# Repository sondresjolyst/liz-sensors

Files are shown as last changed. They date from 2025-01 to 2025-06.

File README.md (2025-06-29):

# ReadTempAndHumidity

## Garge Voltmeter

Garge Voltmeter

### Voltage Divider Calculation for Wemos D1 Mini

To measure a higher voltage than 3.3V using the Wemos D1 Mini's ADC port, you can create a voltage divider with 47kΩ and 4.7kΩ resistors.

#### Voltage Divider Formula

$`V_{out} = V_{in} \times \frac{R2}{(R1 + R2)}`$

##### Precision

The Wemos D1 Mini's ADC can read voltages between 0 and 3.3V and gives a 10-bit reading (0-1024).
To calculate the minimum precision in voltage, one need to divide the maximum voltage by the ADC resolution:
$`\text{Minimum precision} = \frac{3.3V}{1024} \approx 0.00322V`$

The voltage at the ADC pin is approximately 9.09% of the input voltage. When the ADC reading changes by one step (e.g., from 366 to 365), the input voltage changes by:

$`\Delta V_{in} \approx \Delta V_{ADC} \times \frac{R1 + R2}{R2}`$

$`\Delta V_{in} \approx 0.00322V \times \frac{47k\Omega + 4.7k\Omega}{4.7k\Omega} \approx 0.0355V`$

#### Given Values

- $`R1 = 47kΩ`$ (47000Ω)
- $`R2 = 4.7kΩ`$ (4700Ω)
- $`V_{out} = 3.3V`$ (ADC input maximum)

#### Calculate Maximum

$`V_{in} = \frac{V_{out} \times (R1 + R2)}{R2}`$

Plugging in the values:

$`V_{in} = \frac{3.3V \times (47000Ω + 4700Ω)}{4700Ω}`$

$`V_{in} = 3.3V \times \frac{51700Ω}{4700Ω}`$

$`V_{in} \approx 36.3V`$

### Power Consumption Calculation

To estimate the power consumption of the Wemos D1 Mini:

#### Current Draw

Assuming an average current draw of 80mA (0.08A) when performing computations and connected to Wi-Fi.

#### Power Calculation

Using a 5V supply voltage:
$`\text{Power (P)} = \text{Voltage (V)} \times \text{Current (I)}`$

$`P = 5V \times 0.08A = 0.4W`$

#### Battery Life Estimation

With a 13V battery converted to 5V, taking into account the efficiency of the DC-DC converter (assumed to be 90% efficient):

$`\text{Effective Power Required} = \frac{\text{Power Consumption}}{\text{Efficiency}}`$

$`\text{Effective Power Required} = \frac{0.4W}{0.9} \approx 0.444W`$

#### Battery Current

$`I_{13V} = \frac{0.444W}{13V} \approx 0.034A = 34mA`$

#### Battery Capacity

If using a 13V motorcycle battery with a 6Ah (6000mAh) capacity:

Estimated Runtime:

$`\text{Runtime} = \frac{\text{Battery Capacity}}{\text{Current Draw}}`$

$`\text{Runtime} = \frac{6000mAh}{34mA} \approx 176 \, \text{hours}`$

To keep the battery above 40% charge, use only 60% of the battery's capacity:

$`\text{Usable Capacity} = 0.6 \times 72Wh = 43.2Wh`$

Revised Runtime:

$`\text{Runtime} = \frac{43.2Wh}{0.4W} = 108 \, \text{hours}`$

## Garge Sensor BME280

Garge Sensor BME280

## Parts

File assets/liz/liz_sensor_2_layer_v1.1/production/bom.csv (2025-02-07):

Designator | Footprint | Quantity | Value | LCSC Part #
BOOT1, RESET1 | PTS810SJG250SMTRLFS | 2 | PTS810SJM250SMTRLFS | C116501
C1, C3, C4, C7 | 0603 | 4 | 0.1uF | C108079
C10 | 0603 | 1 | 22uF | C86295
C2, C5, C6 | 0603 | 3 | 10uF | C95839
C9 | 0603 | 1 | 10uF | C3039688
D1 | D_SOD-123 | 1 | MM1Z3V3 | C22379456
D3 | 0603 | 1 | LED | C497940
D4, D6 | D_SOD-123 | 2 | B5817W | C7420328
J1 | USB_C_Receptacle_GCT_USB4105-xx-A_16P_TopMnt_Horizontal | 1 | USB_C_Receptacle_USB2.0_16P | C2988369
L2 | RES_CIGT201610_SAM | 1 | 2.2uH | C315717
PS1 | DSG0008A | 1 | TPS62163DSGR | C97534
R1, R2, R3, R8 | 0603 | 4 | 5.1k | C105580
R10, R11, R9 | 0603 | 3 | 10k | C98220
R4 | 0603 | 1 | 100k | C14675
R5 | 0603 | 1 | 33k | C126359
R6 | 0603 | 1 | 1M | C105578
R7 | 0603 | 1 | 200K | C105574
U1 | XCVR_ESP32-S3-MINI-1-N8 | 1 | ESP32-S3-MINI-1-N8 | C2913206
U2 | Diodes_UDFN-10_1.0x2.5mm_P0.5mm | 1 | D3V3XA4B10LP | C1980462
U5 | WSON-6-1EP_2x2mm_P0.65mm_EP1x1.6mm | 1 | TLV75801PDRVR | C2876308

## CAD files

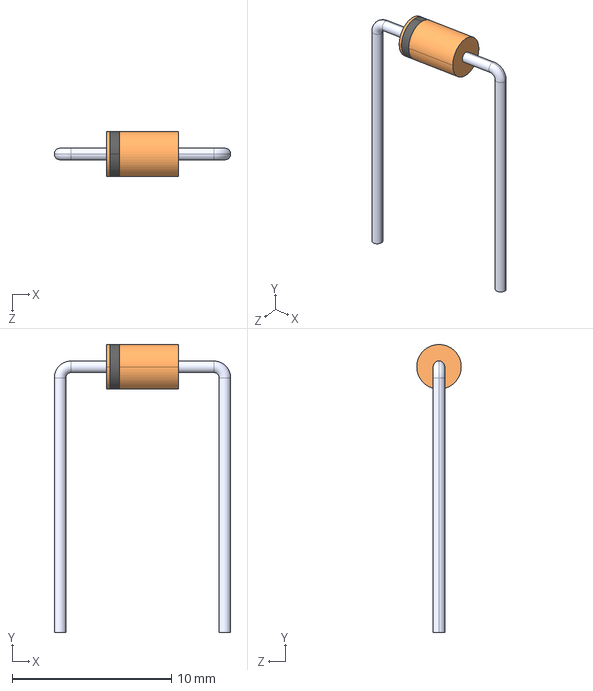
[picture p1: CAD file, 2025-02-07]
assets/kicad/DIOAD1036W78L470D235/1N5819.step
11.1 x 18.1 x 2.80 mm

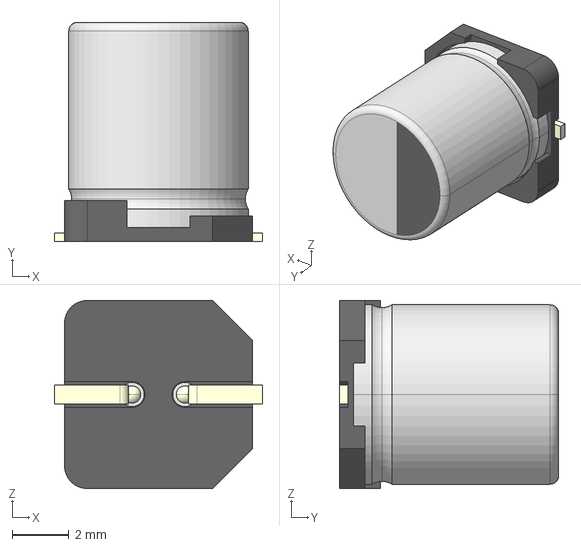
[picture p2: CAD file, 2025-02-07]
assets/kicad/EEE_FK1C221XP/6.3 SIZE CODE D8.stp
7.30 x 7.70 x 6.60 mm

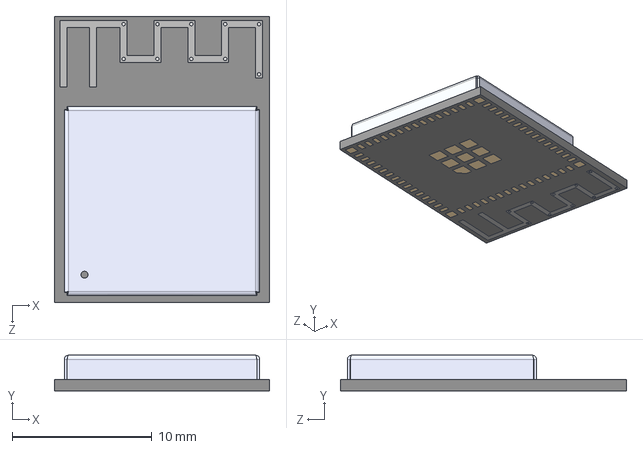
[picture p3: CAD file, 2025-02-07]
assets/kicad/ESP32_S3_MINI_1_N8/ESP32-S3-MINI-1-N8.step
15.4 x 2.55 x 20.5 mm

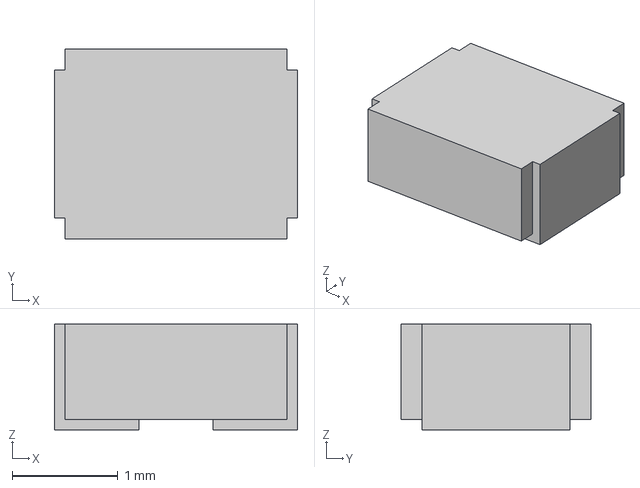
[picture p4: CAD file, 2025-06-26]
assets/kicad/INPAQ WIP201610P-2R2ML/INPAQ WIP201610P-2R2ML v1.step
2.30 x 1.80 x 1.00 mm

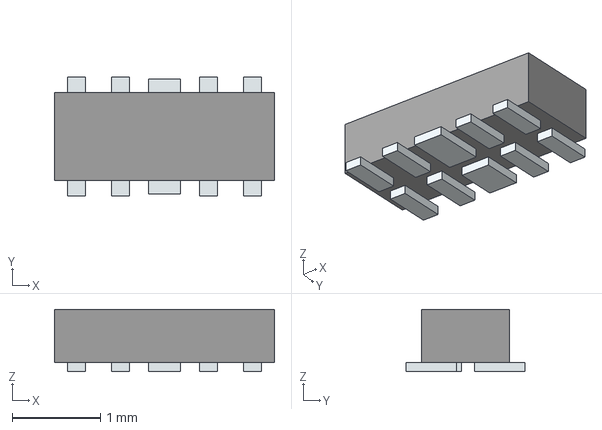
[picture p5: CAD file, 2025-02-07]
assets/kicad/LIB_D3V3XA4B10LP-7/3D_MODEL_D3V3XA4B10LP-7.stp
2.50 x 1.35 x 0.705 mm
Pins

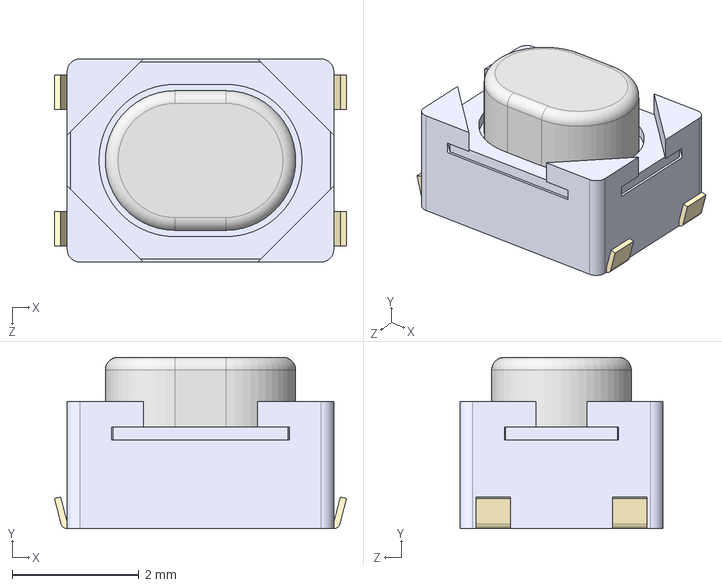
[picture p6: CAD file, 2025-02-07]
assets/kicad/PTS810_SJM_250_SMTR_LFS-1/PTS810_SJM_250_SMTR_LFS.step
4.60 x 2.70 x 3.20 mm

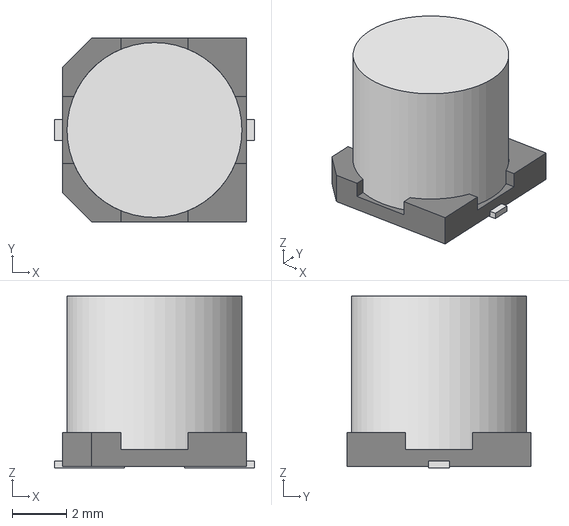
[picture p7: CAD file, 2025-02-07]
assets/kicad/UCD1C101MCL1GS/PCAP_6_3x5_8-ELECT_NCA.step
7.39 x 6.81 x 6.35 mm

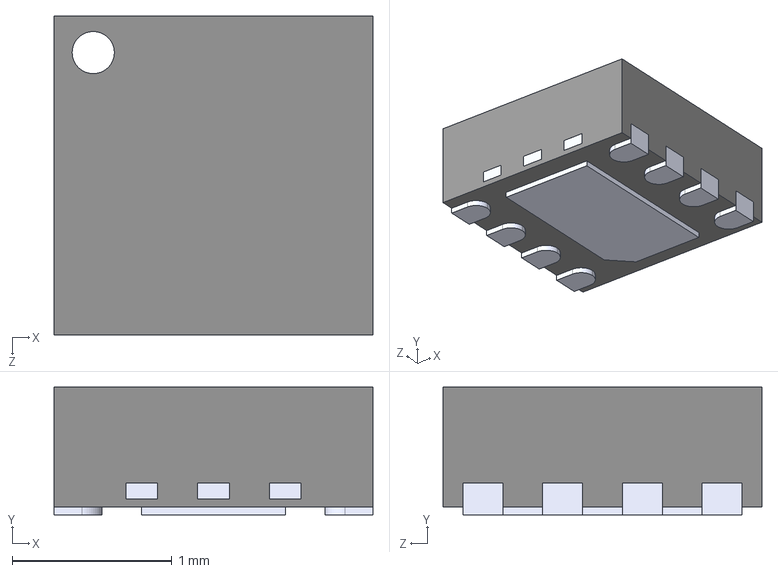
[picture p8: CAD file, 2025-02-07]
assets/kicad/TPS62163DSGR/TPS62163DSGR.step
2.00 x 0.8 x 2.00 mm

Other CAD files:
assets/kicad/PTS810SJK250SMTRLFS/PTS810SJK250SMTRLFS.step
assets/kicad/SW_SPST_PTS810/PTS810 SJK 250 SMTR LFS--3DModel-STEP-56544.STEP
assets/kicad/UCD1C101MCL1GS/PCAP_6_3x5_8-ELECT_NCA.stl

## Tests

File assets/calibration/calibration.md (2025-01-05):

# Calibration data

## Wemos_D1_Mini_30359b

vinTest: 5.34961, multimeter Voltage: 5.02
vinTest: 13.05305, multimeter Voltage: 12.46

b = (ln(12.46) - ln(5.02)) / (ln(13.05305) - ln(5.34961))
b = 1.01917

a = exp(ln(5.02) - b \* ln(5.34961))
a = 0.908698

## Wemos_D1_Mini_6ceb7b

vinTest: 5.31395, multimeter Voltage: 5.02
vinTest: 12.87473, multimeter Voltage: 12.46 !

b = (ln(12.46) - ln(5.02)) / (ln(12.87473) - ln(5.31395))
b = 1.0273

a = exp(ln(5.02) - b \* ln(5.31395))
a = 0.902573

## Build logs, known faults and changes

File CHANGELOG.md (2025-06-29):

# Changelog

## [1.2.0](https://github.com/sondresjolyst/liz-sensors/compare/v1.1.0...v1.2.0) (2025-06-29)

### Features

* deep sleep ([#52](https://github.com/sondresjolyst/liz-sensors/issues/52)) ([0139c0d](https://github.com/sondresjolyst/liz-sensors/commit/0139c0dd5e194e585fd49ba69620a2ce6850fd93))
* esp32 ([aac173f](https://github.com/sondresjolyst/liz-sensors/commit/aac173f91aa43422f035a25af99483b9dd24c71a))
* ota ([#42](https://github.com/sondresjolyst/liz-sensors/issues/42)) ([fa102e5](https://github.com/sondresjolyst/liz-sensors/commit/fa102e535304ba1b2b8679088578786951ce5ac2))
* reconnect wifi ([#41](https://github.com/sondresjolyst/liz-sensors/issues/41)) ([d379210](https://github.com/sondresjolyst/liz-sensors/commit/d379210903855eb51af8a8aa1a10627c74eb0c7d))
* restart esp after 30min in ap mode ([#47](https://github.com/sondresjolyst/liz-sensors/issues/47)) ([b1f367a](https://github.com/sondresjolyst/liz-sensors/commit/b1f367a2116ffc1238ec697edb8ca4a9438ff282))

## [1.1.0](https://github.com/sondresjolyst/ReadTempAndHumidity/compare/v1.0.0...v1.1.0) (2024-12-31)

### Features

* Add disconnect wifi button and update resistor values ([#16](https://github.com/sondresjolyst/ReadTempAndHumidity/issues/16)) ([7f7b2db](https://github.com/sondresjolyst/ReadTempAndHumidity/commit/7f7b2dbf6480bca77c49b0f49c84de614a5afcf4))
* clear discovered devices on mqtt connect ([#15](https://github.com/sondresjolyst/ReadTempAndHumidity/issues/15)) ([44b7ca9](https://github.com/sondresjolyst/ReadTempAndHumidity/commit/44b7ca900ee3a1d1843a49a8f0f2101eacec3b31))
* update liz library ([#13](https://github.com/sondresjolyst/ReadTempAndHumidity/issues/13)) ([82a56c5](https://github.com/sondresjolyst/ReadTempAndHumidity/commit/82a56c53015a5911a2f03a102e0812599baf3a18))
* voltmeter exponential correction ([#10](https://github.com/sondresjolyst/ReadTempAndHumidity/issues/10)) ([520e2b2](https://github.com/sondresjolyst/ReadTempAndHumidity/commit/520e2b2ddef42d0b414009e25ad73d3146d3929d))

## 1.0.0 (2024-11-24)

### Features

* add support for BME280 sensor ([93d0e8c](https://github.com/sondresjolyst/ReadTempAndHumidity/commit/93d0e8c4809605525ba1d0de92667ec27f99ab57))
* add voltmeter function ([ef76b20](https://github.com/sondresjolyst/ReadTempAndHumidity/commit/ef76b20ffd68cb40df00a7c2bb684850c44f1c26))
* restart ESP if temp or humid fail 10 times ([7d7e851](https://github.com/sondresjolyst/ReadTempAndHumidity/commit/7d7e85164cb90c81dfba13be1f3010f54c79e531))

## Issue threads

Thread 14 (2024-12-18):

subscribe to topic again after mosquitto server restart

sondresjolyst, 2024-12-18:
now it check if the connection is lost and reconnects, but it does not subscribe to the topic again.

this can be done by resetting discovered devices on reconnect or subscribing every discovery.
https://github.com/sondresjolyst/ReadTempAndHumidity/blob/82a56c53015a5911a2f03a102e0812599baf3a18/src/main.cpp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

Closed 2024-12-19.

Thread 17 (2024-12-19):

Rename repository

sondresjolyst, 2024-12-19:
The project now support voltage reading, temperature reading and humidity reading. Therefore the repository name should be changed to a more suitable name.

name ideas:
liz-sensors

Closed 2025-01-01.

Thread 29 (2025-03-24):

chore: add the possibility to change sensor name on build

sondresjolyst, 2025-03-24:
make it possible to change sensor name when building the image.
currently all sensors are named wemos_d1_mini... it should be possible wich is not always correct as liz-sensors now support esp32

sondresjolyst, 2025-08-10:
name is now dynamically built

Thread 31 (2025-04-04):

feat: Power sensor with own battery

sondresjolyst, 2025-04-04:
today liz uses 5v from USB or 12v from measuring connection.

look into adding a battery to the liz sensor.

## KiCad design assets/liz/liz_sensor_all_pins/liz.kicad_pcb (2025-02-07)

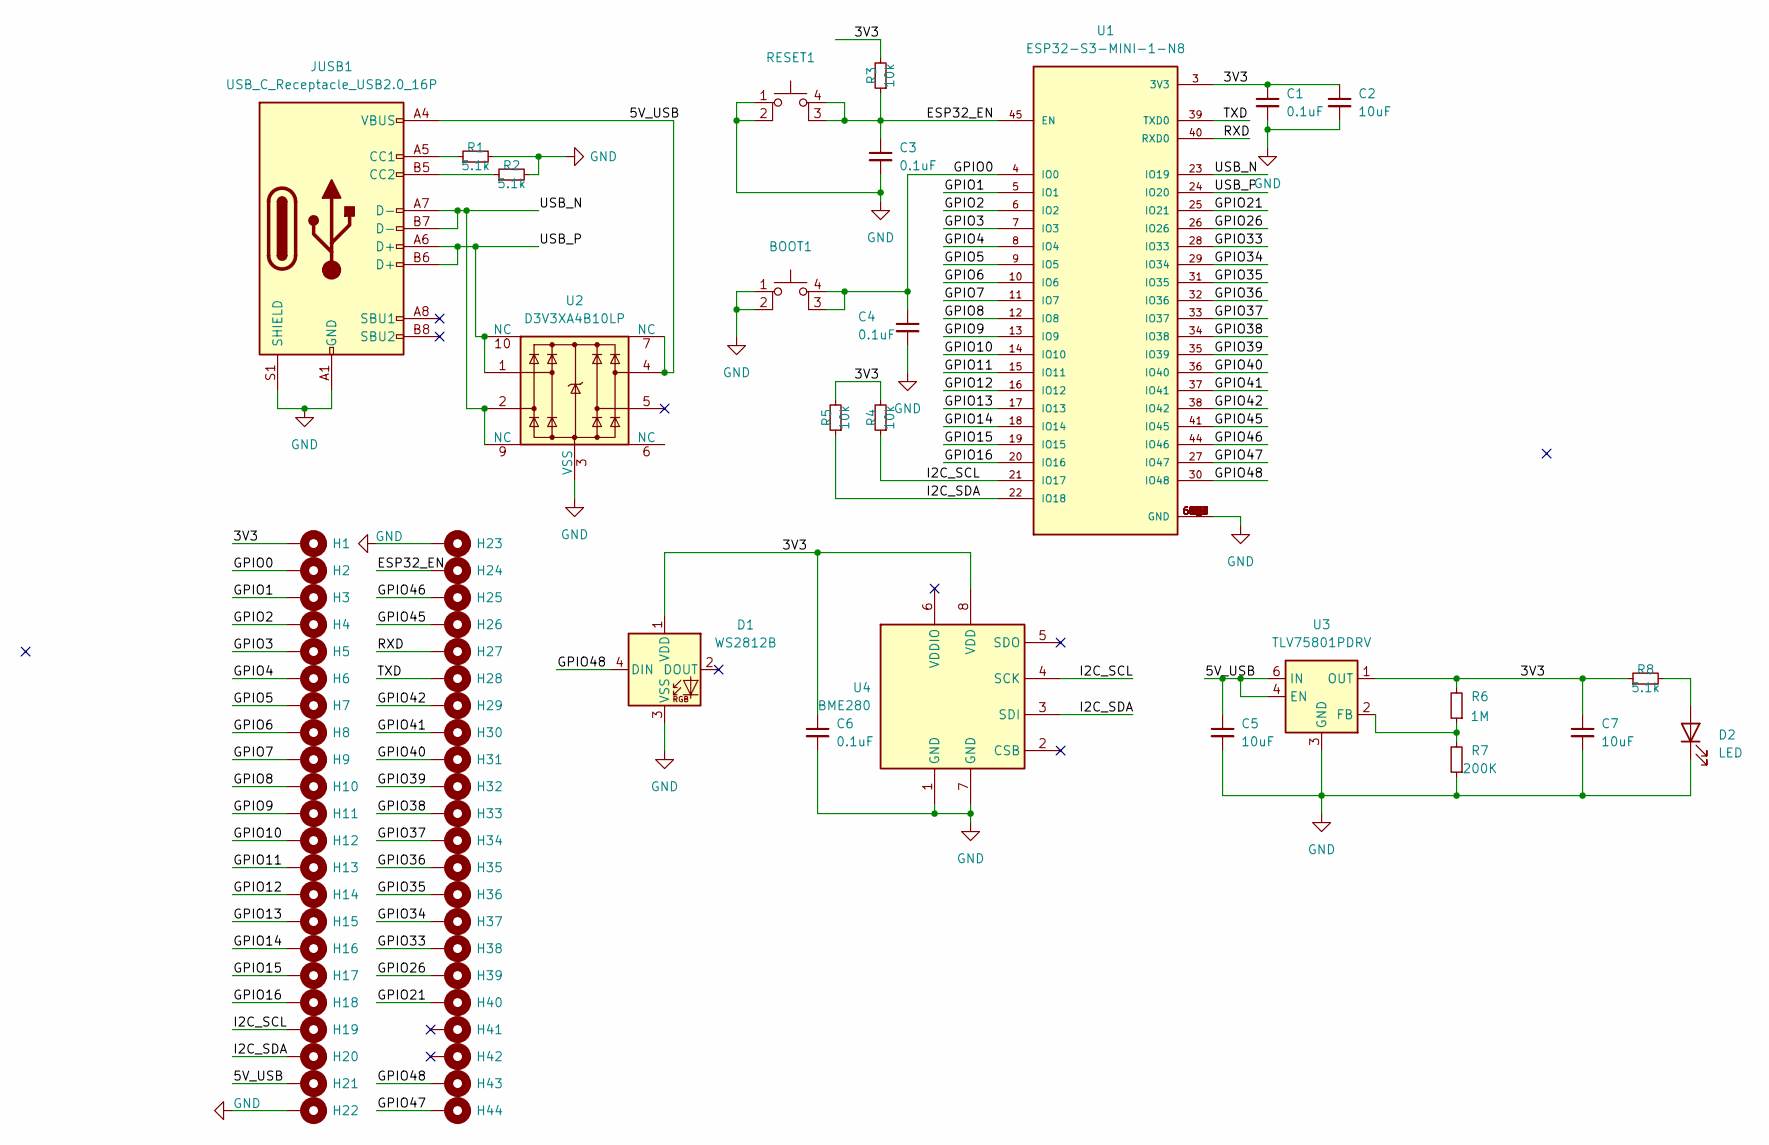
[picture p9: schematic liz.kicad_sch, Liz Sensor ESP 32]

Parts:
BOOT1: SW_SPST_PTS810
C1, C3, C4, C6: 0.1uF; C_0603_1608Metric
C2, C5, C7: 10uF; C_0603_1608Metric
D1: WS2812B; LED_WS2812B_PLCC4_5.0x5.0mm_P3.2mm
D2: LED; LED_0603_1608Metric
H1, H2, H3, H4, H5, H6, H7, H8, H9, H10, H11, H12, H13, H14, H15, H16, H17, H18, H19, H20, H21, H22, H23, H24, H25, H26, H27, H28, H29, H30, H31, H32, H33, H34, H35, H36, H37, H38, H39, H40, H41, H42, H43, H44: TestPoint_THTPad_D1.0mm_Drill0.5mm
JUSB1: USB_C_Receptacle_USB2.0_16P; USB_C_Receptacle_GCT_USB4105-xx-A_16P_TopMnt_Horizontal
R1, R2, R8: 5.1k; R_0603_1608Metric
R3, R4, R5: 10k; R_0603_1608Metric
R6: 1M; R_0603_1608Metric
R7: 200K; R_0603_1608Metric
RESET1: SW_SPST_PTS810
U1: ESP32-S3-MINI-1-N8; XCVR_ESP32-S3-MINI-1-N8; PARTREV v0.6
U2: D3V3XA4B10LP; Diodes_UDFN-10_1.0x2.5mm_P0.5mm
U3: TLV75801PDRV; WSON-6-1EP_2x2mm_P0.65mm_EP1x1.6mm
U4: BME280; Bosch_LGA-8_2.5x2.5mm_P0.65mm_ClockwisePinNumbering

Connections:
/3V3: C1.1, C2.1, C6.1, C7.1, D1.1 (VDD), H1.1, R3.2, R4.2, R5.2, R6.2, R8.1, U1.3 (3V3), U3.1 (OUT), U4.8 (VDD)
/5V_USB: C5.1, H21.1, JUSB1.A4 (VBUS), JUSB1.A9 (VBUS), JUSB1.B4 (VBUS), JUSB1.B9 (VBUS), U2.4, U2.7 (NC), U3.4 (EN), U3.6 (IN)
/ESP32_EN: C3.1, H24.1, R3.1, RESET1.3 (K), RESET1.4 (A), U1.45 (EN)
/GPIO0: BOOT1.3 (K), BOOT1.4 (A), C4.1, H2.1, U1.4 (IO0)
/GPIO1: H3.1, U1.5 (IO1)
/GPIO2: H4.1, U1.6 (IO2)
/GPIO3: H5.1, U1.7 (IO3)
/GPIO4: H6.1, U1.8 (IO4)
/GPIO5: H7.1, U1.9 (IO5)
/GPIO6: H8.1, U1.10 (IO6)
/GPIO7: H9.1, U1.11 (IO7)
/GPIO8: H10.1, U1.12 (IO8)
/GPIO9: H11.1, U1.13 (IO9)
/GPIO10: H12.1, U1.14 (IO10)
/GPIO11: H13.1, U1.15 (IO11)
/GPIO12: H14.1, U1.16 (IO12)
/GPIO13: H15.1, U1.17 (IO13)
/GPIO14: H16.1, U1.18 (IO14)
/GPIO15: H17.1, U1.19 (IO15)
/GPIO16: H18.1, U1.20 (IO16)
/GPIO21: H40.1, U1.25 (IO21)
/GPIO26: H39.1, U1.26 (IO26)
/GPIO33: H38.1, U1.28 (IO33)
/GPIO34: H37.1, U1.29 (IO34)
/GPIO35: H36.1, U1.31 (IO35)
/GPIO36: H35.1, U1.32 (IO36)
/GPIO37: H34.1, U1.33 (IO37)
/GPIO38: H33.1, U1.34 (IO38)
/GPIO39: H32.1, U1.35 (IO39)
/GPIO40: H31.1, U1.36 (IO40)
/GPIO41: H30.1, U1.37 (IO41)
/GPIO42: H29.1, U1.38 (IO42)
/GPIO45: H26.1, U1.41 (IO45)
/GPIO46: H25.1, U1.44 (IO46)
/GPIO47: H44.1, U1.27 (IO47)
/GPIO48: D1.4 (DIN), H43.1, U1.30 (IO48)
/I2C_SCL: H19.1, R4.1, U1.21 (IO17), U4.4 (SCK)
/I2C_SDA: H20.1, R5.1, U1.22 (IO18), U4.3 (SDI)
/RXD: H27.1, U1.40 (RXD0)
/TXD: H28.1, U1.39 (TXD0)
/USB_N: JUSB1.A7 (D-), JUSB1.B7 (D-), U1.23 (IO19), U2.2, U2.9 (NC)
/USB_P: JUSB1.A6 (D+), JUSB1.B6 (D+), U1.24 (IO20), U2.1, U2.10 (NC)
GND: BOOT1.1, BOOT1.2, C1.2, C2.2, C3.2, C4.2, C5.2, C6.2, C7.2, D1.3 (VSS), D2.1 (K), H22.1, H23.1, JUSB1.A1 (GND), JUSB1.A12 (GND), JUSB1.B1 (GND), JUSB1.B12 (GND), JUSB1.S1 (SHIELD), R1.2, R2.2, R7.1, RESET1.1, RESET1.2, U1.1 (GND), U1.2 (GND), U1.42 (GND), U1.43 (GND), U1.46 (GND), U1.47 (GND), U1.48 (GND), U1.49 (GND), U1.50 (GND), U1.51 (GND), U1.52 (GND), U1.53 (GND), U1.54 (GND), U1.55 (GND), U1.56 (GND), U1.57 (GND), U1.58 (GND), U1.59 (GND), U1.60 (GND), U1.61 (GND), U1.61_1 (GND), U1.61_2 (GND), U1.61_3 (GND), U1.61_4 (GND), U1.61_5 (GND), U1.61_6 (GND), U1.61_7 (GND), U1.61_8 (GND), U1.62 (GND), U1.63 (GND), U1.64 (GND), U1.65 (GND), U2.3 (VSS), U2.8 (VSS), U3.3 (GND), U3.7 (GND), U4.1 (GND), U4.7 (GND)
unnamed: D2.2 (A), R8.2
unnamed: JUSB1.A5 (CC1), R1.1
unnamed: JUSB1.B5 (CC2), R2.1
unnamed: R6.1, R7.2, U3.2 (FB)

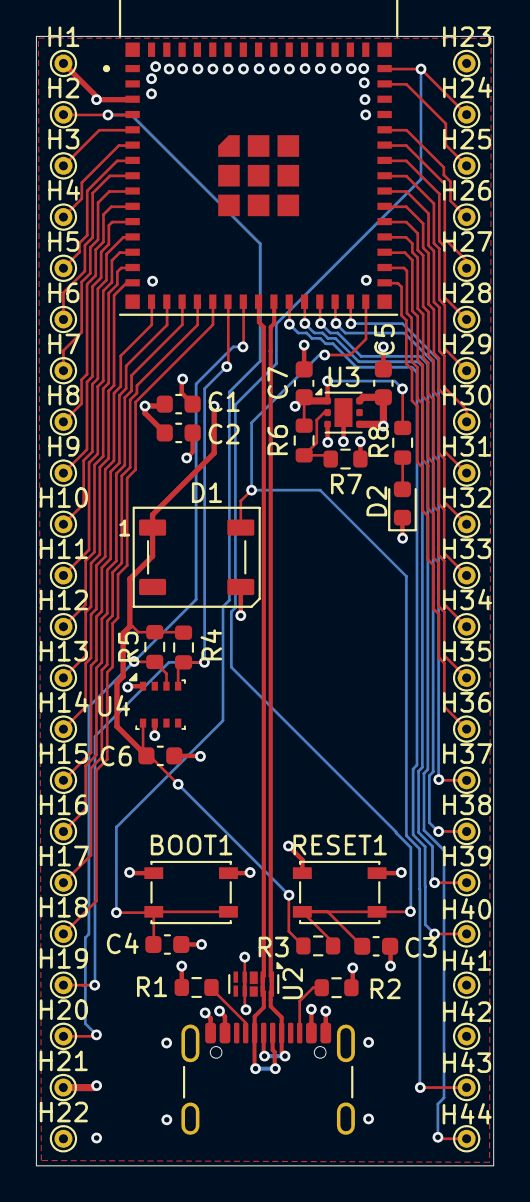
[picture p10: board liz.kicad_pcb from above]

Board: 4 copper layers, 25.4 x 62.7 mm, 68 parts (0 on the bottom side), 47 nets.

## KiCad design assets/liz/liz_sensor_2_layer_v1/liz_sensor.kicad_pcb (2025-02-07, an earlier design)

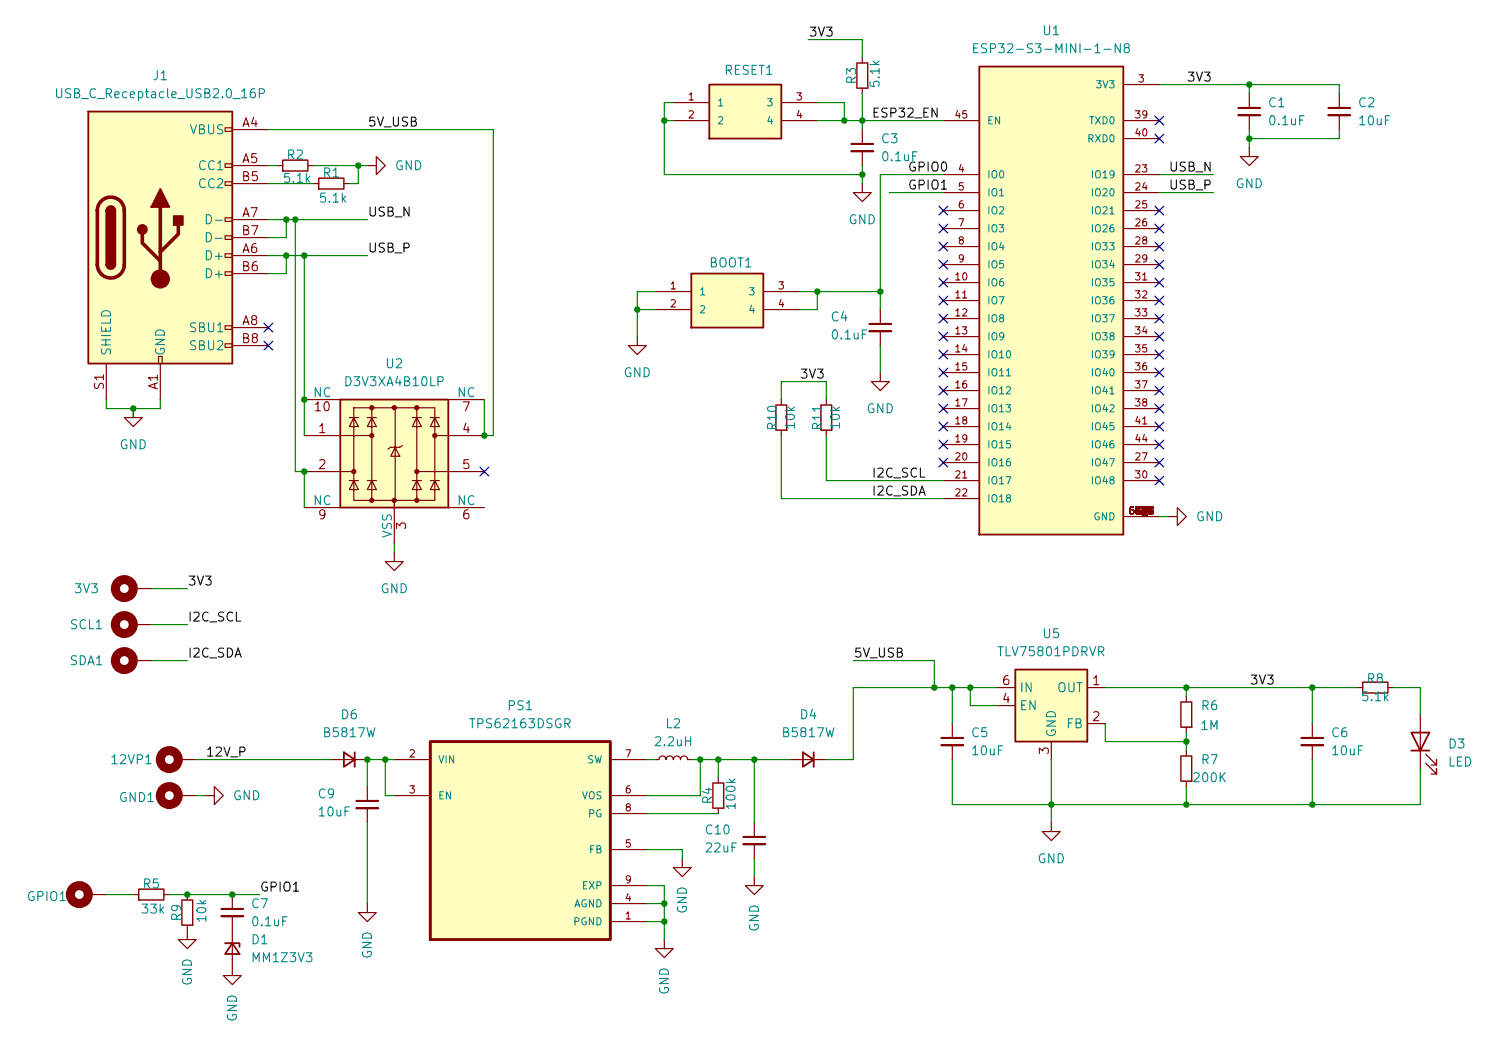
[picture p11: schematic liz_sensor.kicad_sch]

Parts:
3V3, 12VP1: TestPoint_THTPad_D1.0mm_Drill0.5mm
BOOT1: PTS810SJM250SMTRLFS; PTS810SJG250SMTRLFS; MANUFACTURER_PART_NUMBER PTS810SJK250SMTRLFS; JLCPCB Part # C116501
C1, C3, C4, C7: 0.1uF; C_0603_1608Metric; Part# CC0603KRX7R7BB104; JLCPCB Part # C108079
C2, C5, C6: 10uF; C_0603_1608Metric; Part# CL10A106KQ8NNNC; JLCPCB Part # C95839
C9: 10uF; C_0603_1608Metric; Part# CL10X106MO8NRNC; JLCPCB Part # C3039688
C10: 22uF; C_0603_1608Metric; Part# CL10A226MP8NUNE; JLCPCB Part # C86295
D1: MM1Z3V3; D_SOD-123; Part# MM1Z3V3; JLCPCB Part # C22379456
D3: LED; LED_0603_1608Metric; Part# HL-PST-1608H203BC; JLCPCB Part # C497940
D4, D6: B5817W; D_SOD-123; Part# B5817W; JLCPCB Part # C7420328
GND1: TestPoint_THTPad_D1.0mm_Drill0.5mm
GPIO1: TestPoint_THTPad_D1.0mm_Drill0.5mm
J1: USB_C_Receptacle_USB2.0_16P; USB_C_Receptacle_GCT_USB4105-xx-A_16P_TopMnt_Horizontal; Part# GT-USB-7010ASV; JLCPCB Part # C2988369
L2: 2.2uH; RES_CIGT201610_SAM; Part# WIP201610P-2R2ML; JLCPCB Part # C315717
PS1: TPS62163DSGR; DSG0008A; PARTREV E; JLCPCB Part # C97534
R1, R2, R3, R8: 5.1k; R_0603_1608Metric; Part# RC0603FR-075K1L; JLCPCB Part # C105580
R4: 100k; R_0603_1608Metric; Part# RC0603FR-07100KL; JLCPCB Part # C14675
R5: 33k; R_0603_1608Metric; Part# RC0603FR-0733KL; JLCPCB Part # C126359
R6: 1M; R_0603_1608Metric; Part# RC0603FR-071ML; JLCPCB Part # C105578
R7: 200K; R_0603_1608Metric; Part# RC0603FR-07200KL; JLCPCB Part # C105574
R9, R10, R11: 10k; R_0603_1608Metric; Part# RC0603FR-0710KL; JLCPCB Part # C98220
RESET1: PTS810SJM250SMTRLFS; PTS810SJG250SMTRLFS; MANUFACTURER_PART_NUMBER PTS810SJK250SMTRLFS; JLCPCB Part # C116501
SCL1: TestPoint_THTPad_D1.0mm_Drill0.5mm
SDA1: TestPoint_THTPad_D1.0mm_Drill0.5mm
U1: ESP32-S3-MINI-1-N8; XCVR_ESP32-S3-MINI-1-N8; PARTREV v0.6; JLCPCB Part # C2913206
U2: D3V3XA4B10LP; Diodes_UDFN-10_1.0x2.5mm_P0.5mm; Part# D3V3XA4B10LP-7; JLCPCB Part # C1980462
U5: TLV75801PDRVR; WSON-6-1EP_2x2mm_P0.65mm_EP1x1.6mm; Part# TLV75801PDRVR; JLCPCB Part # C2876308

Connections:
/3V3: 3V3.1, C1.1, C2.1, C6.1, R3.2, R6.2, R8.1, R10.2, R11.2, U1.3 (3V3), U5.1 (OUT)
/5V_USB: C5.1, D4.1 (K), J1.A4 (VBUS), J1.A9 (VBUS), J1.B4 (VBUS), J1.B9 (VBUS), U2.4, U2.7 (NC), U5.4 (EN), U5.6 (IN)
/12V_P: 12VP1.1, D6.2 (A)
/ESP32_EN: C3.1, R3.1, RESET1.3, RESET1.4, U1.45 (EN)
/GPIO0: BOOT1.3, BOOT1.4, C4.1, U1.4 (IO0)
/GPIO1: C7.1, R5.2, R9.2, U1.5 (IO1)
/I2C_SCL: R11.1, SCL1.1, U1.21 (IO17)
/I2C_SDA: R10.1, SDA1.1, U1.22 (IO18)
/USB_N: J1.A7 (D-), J1.B7 (D-), U1.23 (IO19), U2.2, U2.9 (NC)
/USB_P: J1.A6 (D+), J1.B6 (D+), U1.24 (IO20), U2.1, U2.10 (NC)
GND: BOOT1.1, BOOT1.2, C1.2, C2.2, C3.2, C4.2, C5.2, C6.2, C9.2, C10.2, D1.2 (A), D3.1 (K), GND1.1, J1.A1 (GND), J1.A12 (GND), J1.B1 (GND), J1.B12 (GND), J1.S1 (SHIELD), PS1.1 (PGND), PS1.4 (AGND), PS1.5 (FB), PS1.9 (EXP), PS1.V, R1.2, R2.2, R7.1, R9.1, RESET1.1, RESET1.2, U1.1 (GND), U1.2 (GND), U1.42 (GND), U1.43 (GND), U1.46 (GND), U1.47 (GND), U1.48 (GND), U1.49 (GND), U1.50 (GND), U1.51 (GND), U1.52 (GND), U1.53 (GND), U1.54 (GND), U1.55 (GND), U1.56 (GND), U1.57 (GND), U1.58 (GND), U1.59 (GND), U1.60 (GND), U1.61 (GND), U1.61_1 (GND), U1.61_2 (GND), U1.61_3 (GND), U1.61_4 (GND), U1.61_5 (GND), U1.61_6 (GND), U1.61_7 (GND), U1.61_8 (GND), U1.62 (GND), U1.63 (GND), U1.64 (GND), U1.65 (GND), U2.3 (VSS), U2.8 (VSS), U5.3 (GND), U5.7 (GND)
unnamed: C7.2, D1.1 (K)
unnamed: D3.2 (A), R8.2
unnamed: C10.1, D4.2 (A), L2.2, PS1.6 (VOS), R4.2
unnamed: C9.1, D6.1 (K), PS1.2 (VIN), PS1.3 (EN)
unnamed: GPIO1.1, R5.1
unnamed: J1.A5 (CC1), R2.1
unnamed: J1.B5 (CC2), R1.1
unnamed: PS1.8 (PG), R4.1
unnamed: L2.1, PS1.7 (SW)
unnamed: R6.1, R7.2, U5.2 (FB)

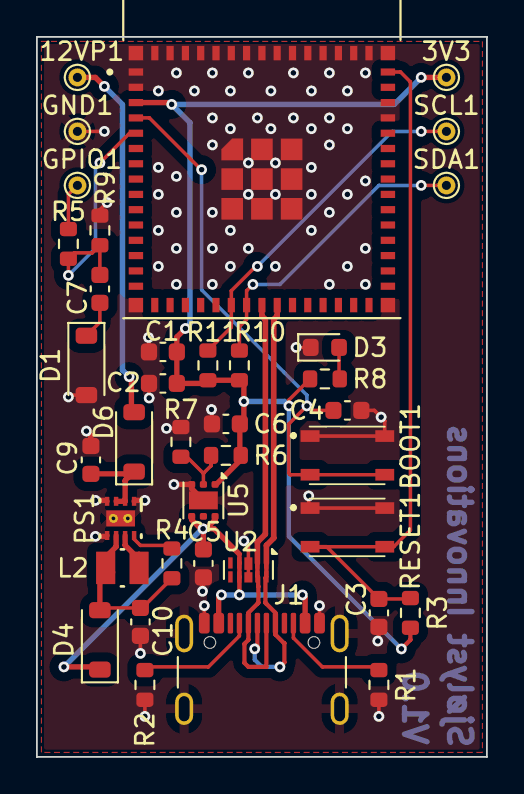
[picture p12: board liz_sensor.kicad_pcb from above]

Board: 2 copper layers, 25.0 x 40.0 mm, 38 parts (0 on the bottom side), 21 nets.

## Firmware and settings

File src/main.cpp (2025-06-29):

// Copyright (c) 2023-2025 Sondre Sjølyst

#include <Arduino.h>
#include <DHT.h>
#include <DNSServer.h>
#include <EEPROM.h>
#include <HTTPClient.h>
#include <WebServer.h>
#include <WiFi.h>
#include <Wire.h>

#include <cstdint>
#include <cstring>
#include <regex>
#include <string>

#include "./config/arduino_secrets.h"
#include "./liz.h"
#include "controllers/SensorController.h"
#include "controllers/VoltmeterController.h"
#include "helpers/EEPROMHelper.h"
#include "helpers/MQTTHelper.h"
#include "helpers/OTAHelper.h"
#include "helpers/PRINTHelper.h"
#include "helpers/WIZHelper.h"
#include "helpers/WiFiHelper.h"
#include "web/WebSite.h"

#ifndef SENSOR_TYPE
#define SENSOR_TYPE "bme"  // "bme" or "dht"
#endif

#ifndef GARGE_TYPE
#define GARGE_TYPE "sensor"  // "voltmeter" or "sensor"
#endif

const char *MQTT_BROKER = SECRET_MQTTBROKER;
const char *MQTT_PASS = SECRET_MQTTPASS;
const char *MQTT_USER = SECRET_MQTTUSER;
const int MQTT_PORT = SECRET_MQTTPORT;
bool isAPMode = false;

constexpr uint8_t DHTTYPE = DHT11;
constexpr float TEMP_HUMID_DIFF = 10.0;
constexpr int DHT_SENSOR_PIN = 2;
constexpr int DNS_PORT = 53;
constexpr int EEPROM_PASSWORD_END = 96;
constexpr int EEPROM_PASSWORD_START = 32;
constexpr int EEPROM_SSID_END = 31;
constexpr int EEPROM_SSID_START = 0;
constexpr int LED_BLINK_COUNT = 10;
constexpr int LED_BLINK_DELAY = 1000;
constexpr int RESET_BUTTON_GPO = 4;
constexpr int RESET_PRESS_DURATION = 5000;
constexpr int SERIAL_PORT = 9600;
constexpr int WEBSITE_PORT = 80;
constexpr int WIFI_DELAY = 1000;
constexpr int WIFI_TRIES = 15;
constexpr int port = 38899;
constexpr size_t EEPROM_SIZE = 512;

Adafruit_BME280 bme;
DHT dht(DHT_SENSOR_PIN, DHTTYPE, 11);
WebServer server(WEBSITE_PORT);
ResetWiFi resetWiFi(RESET_BUTTON_GPO, RESET_PRESS_DURATION);
OTAHelper *otaHelper = nullptr;
WiFiClient serverClient;
PRINTHelper printHelper(&serverClient);

String CHIP_ID_STRING;
String MQTT_HOSTNAME_STRING;
const char *MQTT_HOSTNAME = nullptr;
String MQTT_STATETOPIC;
String WIFI_NAME;

String toLowerFunc(const char *s) {
  String tmp = String(s);
  tmp.toLowerCase();
  return tmp;
}

String productNameLower = toLowerFunc(PRODUCER_NAME);
String gargeTypeLower = toLowerFunc(GARGE_TYPE);
String sensorTypeLower = toLowerFunc(SENSOR_TYPE);
const String OTA_PRODUCT_NAME =
    productNameLower + "_" + gargeTypeLower + "_" + sensorTypeLower;

void gargeSetupAP() {
  setupAP();
  isAPMode = true;
}

void setupTime() {
  configTime(0, 0, "pool.ntp.org");
  Serial.print("Waiting for NTP time sync...");
  time_t now = time(nullptr);
  int64_t start = millis();
  const int64_t timeout = 10000;  // 10 seconds

  while ((now < 8 * 3600 * 2) && (millis() - start < timeout)) {
    delay(500);
    Serial.print(".");
    now = time(nullptr);
    if (WiFi.status() != WL_CONNECTED) {
      Serial.println(
          "\nWiFi disconnected during NTP sync. Aborting time setup.");
      return;
    }
  }
  if (now < 8 * 3600 * 2) {
    Serial.println("\nNTP sync timeout. Time not set.");
  } else {
    Serial.println(" done!");
  }
}

bool isNightTime() {
  time_t now = time(nullptr);
  struct tm timeinfo;
  localtime_r(&now, &timeinfo);
  int hour = timeinfo.tm_hour;
  return (hour >= 2 && hour < 4);
}

void setup() {
  Serial.begin(SERIAL_PORT);
  delay(100);

  uint64_t chipId = ESP.getEfuseMac();
  CHIP_ID_STRING = String(chipId, HEX);
  MQTT_HOSTNAME_STRING = "Wemos_D1_Mini_" + CHIP_ID_STRING;
  MQTT_HOSTNAME = MQTT_HOSTNAME_STRING.c_str();
  MQTT_STATETOPIC = "home/storage/" + String(MQTT_HOSTNAME) + "/state";
  WIFI_NAME = "Garge " + String(CHIP_ID_STRING);

  Serial.println("Disconnecting WiFi");
  WiFi.disconnect();

  EEPROMHelper_begin(EEPROM_SIZE);
  delay(10);

  pinMode(LED_BUILTIN, OUTPUT);
  Serial.println("Starting...");
  Serial.println("Reading EEPROM...");

  String EEPROM_SSID = readEEPROM(EEPROM_SSID_START, EEPROM_SSID_END);
  String EEPROM_PASSWORD =
      readEEPROM(EEPROM_PASSWORD_START, EEPROM_PASSWORD_END);

  if (EEPROM_SSID.isEmpty() || EEPROM_SSID.length() < 2 ||
      std::all_of(EEPROM_SSID.begin(), EEPROM_SSID.end(),
                  [](char c) { return c == static_cast<char>(0xFF); })) {
    Serial.println("SSID not found or invalid in EEPROM. Starting AP...");
    gargeSetupAP();
    server.on("/", handleRoot);
    server.on("/submit", HTTP_POST, handleSubmit);
    server.on("/clear-wifi", HTTP_POST, handleClearWiFi);
    server.begin();
    return;
  }

  Serial.printf("Attempting to connect to SSID: %s\n", EEPROM_SSID.c_str());
  if (connectWifi(EEPROM_SSID, EEPROM_PASSWORD)) {
    Serial.println("WiFi connected");
    Serial.print("IP address: ");
    Serial.println(WiFi.localIP());

    setupTime();

    connectToMQTT();
    if (strcmp(GARGE_TYPE, "sensor") == 0) {
      environmentalSensorSetup(SENSOR_TYPE);
    } else if (strcmp(GARGE_TYPE, "voltmeter") == 0) {
      voltageSensorSetup();
    } else {
      Serial.println("Please set GARGE_TYPE");
    }

    server.on("/", webpage_status);  // Status page handler

    if (otaHelper != nullptr) {
      delete otaHelper;
    }

    otaHelper = new OTAHelper();
    otaHelper->setup();

    otaHelper->checkAndUpdateFromManifest(OTA_MANIFEST_URL,
                                          OTA_PRODUCT_NAME.c_str(), VERSION);

    wizSetup();
  } else {
    gargeSetupAP();
    server.on("/", handleRoot);  // Setup page handler
  }
  server.on("/submit", HTTP_POST, handleSubmit);
  server.on("/clear-wifi", HTTP_POST, handleClearWiFi);
  server.begin();

  Serial.println(OTA_PRODUCT_NAME + " " + VERSION + " started");
}

void blinkLED(int count) {
  static uint32_t lastToggleTime = 0;
  static int blinkCount = 0;
  static bool ledState = LOW;

  if (millis() - lastToggleTime >= LED_BLINK_DELAY) {
    ledState = !ledState;
    digitalWrite(LED_BUILTIN, ledState);

    lastToggleTime = millis();

    if (ledState == LOW) {
      blinkCount++;
      if (blinkCount >= count) {
        blinkCount = 0;
      }
    }
  }
}

// Filter out "SOCKET" or "SHRGBC"
bool isWizDevice(const std::string &moduleName) {
  return moduleName.find("SOCKET") != std::string::npos ||
         moduleName.find("SHRGBC") != std::string::npos;
}

void discoverAndSubscribe() {
  // Get the current discoveredDevices
  auto oldDiscoveredDevices = liz::getDiscoveredDevices();
  // Discover devices
  auto discoveredDevices = liz::discover(port, 60000);

  // Only subscribe if a new device has been discovered
  for (const auto &device : discoveredDevices) {
    // Check if the device is not in oldDiscoveredDevices
    if (std::find(oldDiscoveredDevices.begin(), oldDiscoveredDevices.end(),
                  device) == oldDiscoveredDevices.end()) {
      std::string deviceIP = std::get<0>(device);
      std::string deviceMac = std::get<1>(device);
      std::string moduleName = std::get<2>(device);

      if (isWizDevice(moduleName)) {
        std::string deviceName = "wiz_" + moduleName + "_" + deviceMac;
        sendMQTTWizDiscoveryMsg(deviceIP, deviceName);

        std::string stateTopic = "home/storage/" + deviceName + "/set";
        client.subscribe(stateTopic.c_str());
      }
    }
  }
}

void loop() {
  if (isAPMode) {
    server.handleClient();
    // Restart after 30 minutes in AP mode
    static uint32_t apStartTime = 0;
    if (apStartTime == 0) {
      apStartTime = millis();
    }
    if (millis() - apStartTime > 30UL * 60UL * 1000UL) {  // 30 minutes
      Serial.println("Restarting after 30 minutes in AP mode");
      ESP.restart();
    }
    return;
  }

  if (WiFi.status() != WL_CONNECTED) {
    static int16_t lastAttempt = 0;
    if (millis() - lastAttempt > 5000) {
      Serial.println("WiFi lost, attempting reconnect...");
      String EEPROM_SSID = readEEPROM(EEPROM_SSID_START, EEPROM_SSID_END);
      String EEPROM_PASSWORD =
          readEEPROM(EEPROM_PASSWORD_START, EEPROM_PASSWORD_END);
      connectWifi(EEPROM_SSID, EEPROM_PASSWORD);
      lastAttempt = millis();
    }
    server.handleClient();
    return;
  }

  if ((mqttStatus() == false)) {
    Serial.print("Connecting to MQTT");
    connectToMQTT();
  }

  if (otaHelper != nullptr) {
    otaHelper->loop();
  }

  static int64_t lastOtaCheck = 0;
  const int64_t otaCheckInterval = 60UL * 60UL * 1000UL;  // 1 hour

  if (millis() - lastOtaCheck > otaCheckInterval) {
    lastOtaCheck = millis();
    if (isNightTime()) {
      otaHelper->checkAndUpdateFromManifest(OTA_MANIFEST_URL,
                                            OTA_PRODUCT_NAME.c_str(), VERSION);
    }
  }

  handleTelnet();
  server.handleClient();
  resetWiFi.update();
  blinkLED(LED_BLINK_COUNT);
  client.loop();
  if (strcmp(GARGE_TYPE, "sensor") == 0) {
    readAndWriteEnvironmentalSensors(SENSOR_TYPE);
  } else if (strcmp(GARGE_TYPE, "voltmeter") == 0) {
    // Only run once per wakeup for voltmeter, then deep sleep is handled in
    // controller
    readAndWriteVoltageSensor();
    return;
  }
  discoverAndSubscribe();
}

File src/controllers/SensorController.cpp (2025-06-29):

// Copyright (c) 2023-2025 Sondre Sjølyst

#include "SensorController.h"

#ifndef I2C_SDA_PIN
#define I2C_SDA_PIN 18
#endif

#ifndef I2C_SCL_PIN
#define I2C_SCL_PIN 17
#endif

float BMEtempOffset = -3.49;
float BMEhumidOffset = 15;

float DHTtempOffset = -3;
float DHThumidOffset = 6;

float averageHumid = 0;
float averageTemp = 0;
float humidReadings[READING_BUFFER];
float tempReadings[READING_BUFFER];
float totalHumid = 0;
float totalTemp = 0;
int readIndex = 0;

float currentTempReadings = 0;
float currentHumidReadings = 0;
int32_t failedTempReadings = 0;
int32_t failedHumidReadings = 0;

void environmentalSensorSetup(const char *sensorType) {
  if (strcmp(sensorType, "dht") == 0) {
    Serial.printf("Sensor type is: %s\n", sensorType);
    dht.begin();

    for (int i = 0; i < READING_BUFFER; i++) {
      tempReadings[i] = dht.readTemperature() + DHTtempOffset;
      humidReadings[i] = dht.readHumidity() + DHThumidOffset;
      totalTemp += tempReadings[i];
      totalHumid += humidReadings[i];
    }
  } else if (strcmp(sensorType, "bme") == 0) {
    Serial.printf("Sensor type is: %s\n", sensorType);
    Wire.begin(I2C_SDA_PIN, I2C_SCL_PIN);
    if (!bme.begin(0x76)) {
      Serial.println("Could not find a valid BME280 sensor, check wiring!");
      while (1) {
      }
    }
    for (int i = 0; i < READING_BUFFER; i++) {
      tempReadings[i] = bme.readTemperature() + BMEtempOffset;
      humidReadings[i] = bme.readHumidity() + BMEhumidOffset;
      totalTemp += tempReadings[i];
      totalHumid += humidReadings[i];
    }
  } else {
    Serial.print("Error: No sensor type selected!");
  }
}

void checkAndRestartIfFailed(float *reading, int32_t *failedReadings) {
  printHelper.println("Checking if reading failed");
  if (reading == nullptr || std::isnan(*reading)) {
    printHelper.printf("Reading: %s", String(*reading));
    (*failedReadings) += 1;
    printHelper.printf("Failed count: %s", String(*failedReadings));
    if (*failedReadings >= 10) {
      ESP.restart();
    }
  } else {
    printHelper.println("Reading OK");
    printHelper.printf("Reading: %s", String(*reading));
    *failedReadings = 0;
  }
}

void readAndWriteEnvironmentalSensors(const char *sensorType) {
  static uint32_t lastToggleTime = 0;

  if (millis() - lastToggleTime >= READ_DELAY) {
    int arrayLength = sizeof(tempReadings) / sizeof(tempReadings[0]);

    lastToggleTime = millis();

    totalTemp -= tempReadings[readIndex];
    totalHumid -= humidReadings[readIndex];

    if (strcmp(sensorType, "dht") == 0) {
      currentTempReadings = dht.readTemperature();
      currentHumidReadings = dht.readHumidity();

      tempReadings[readIndex] = currentTempReadings + DHTtempOffset;
      humidReadings[readIndex] = currentHumidReadings + DHThumidOffset;
    }
    if (strcmp(sensorType, "bme") == 0) {
      currentTempReadings = bme.readTemperature();
      currentHumidReadings = bme.readHumidity();

      tempReadings[readIndex] = currentTempReadings + BMEtempOffset;
      humidReadings[readIndex] = currentHumidReadings + BMEhumidOffset;
    }

    totalTemp += tempReadings[readIndex];
    totalHumid += humidReadings[readIndex];

    checkAndRestartIfFailed(&totalTemp, &failedTempReadings);
    checkAndRestartIfFailed(&currentHumidReadings, &failedHumidReadings);

    // Debugging
    printHelper.print("tempReadings: ");
    printHelper.println(String(tempReadings[readIndex]));
    printHelper.print("humidReadings: ");
    printHelper.println(String(humidReadings[readIndex]));
    printHelper.print("totalTemp: ");
    printHelper.println(String(totalTemp));
    printHelper.print("totalHumid: ");
    printHelper.println(String(totalHumid));

    readIndex = (readIndex + 1) % arrayLength;

    // Debugging
    printHelper.print("readIndex: ");
    printHelper.println(String(readIndex));
    printHelper.print("arrayLength: ");
    printHelper.println(String(arrayLength));

    averageTemp = totalTemp / arrayLength;
    averageHumid = totalHumid / arrayLength;

    DynamicJsonDocument doc(1024);
    char buffer[256];

    doc["temperature"] = averageTemp;
    doc["humidity"] = averageHumid;

    size_t n = serializeJson(doc, buffer);

    bool published = client.publish(MQTT_STATETOPIC.c_str(), buffer, n);

    Serial.println("Published: ");
    Serial.println(published);
    // Debugging
    printHelper.print("Published: ");
    printHelper.println(String(published));

    Serial.print("Temperature: ");
    Serial.print(averageTemp);
    Serial.println(" °C");
    // Debugging
    printHelper.print("averageTemp: ");
    printHelper.println(String(averageTemp));

    Serial.print("Humidity: ");
    Serial.print(averageHumid);
    Serial.println(" %");
    // Debugging
    printHelper.print("averageHumid: ");
    printHelper.println(String(averageHumid));
  }
}

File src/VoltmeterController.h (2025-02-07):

// Copyright (c) 2023-2025 Sondre Sjølyst

#ifndef SRC_VOLTMETERCONTROLLER_H_
#define SRC_VOLTMETERCONTROLLER_H_

#include <Arduino.h>
#include <ArduinoJson.h>
#include <PubSubClient.h>

#include "PRINTHelper.h"

extern PubSubClient client;
extern String MQTT_STATETOPIC;
extern PRINTHelper printHelper;

const int ANALOG_IN_PIN = A0;
const int ANALOG_RESOLUTION = 4096;     // 10-bit resolution
const float ANALOG_VOLTAGE = 3.32;      // Reference voltage for ESP32 ADC
const float R1 = 33000.0;               // 47kΩ
const float R2 = 10000.0;                // 4.7kΩ
const float CORRECTION_FACTOR = 1.218;  // multimeter voltage / voltageMeasured

// Corrected constants for exponential correction
// Constants a and b are calculated based on curve fitting using known points:
// Point 1: (Measured Voltage: 5.31395, Actual Voltage: 5.03)
// Point 2: (Measured Voltage: 13.05305, Actual Voltage: 12.59)
// Steps to calculate a and b:
// 1. Convert the known points to natural logarithms.
// 2. Solve the system of linear equations to find b.
// 3. Use b to solve for a.
//
// Using points (5.31395, 5.03) and (13.05305, 12.59):
// ln(5.03) = ln(a) + b * ln(5.31395)
// ln(12.59) = ln(a) + b * ln(13.05305)
//
// Solve for b:
// b = (ln(12.59) - ln(5.03)) / (ln(13.05305) - ln(5.31395))
// b ≈ 1.02092
//
// Solve for a:
// a = exp(ln(5.03) - b * ln(5.31395))
// a ≈ 0.91406
const float a = 0.91406;
const float b = 1.02092;

const int READ_VOLTAGE_DELAY = 60000;
const int READING_VOLTAGE_BUFFER = 5;
float averageVoltage = 0;
float voltageReadings[READING_VOLTAGE_BUFFER];
float totalVoltage = 0;
int readVoltageIndex = 0;

float currentVoltageReadings = 0;
int32_t failedVoltageReadings = 0;

float readVoltage() {
  int sensorValue = analogRead(ANALOG_IN_PIN);
  Serial.print("Sensor Value: ");
  Serial.println(sensorValue);

  printHelper.print("sensorValue: ");
  printHelper.print(String(sensorValue));
  printHelper.println(" V");

  // Calculate the measured voltage at the divider output
  float voltageMeasured = (ANALOG_VOLTAGE / ANALOG_RESOLUTION) * sensorValue;
  Serial.print("voltageMeasured: ");
  Serial.print(voltageMeasured, 5);
  Serial.println(" V");

  printHelper.print("voltageMeasured: ");
  printHelper.print(String(voltageMeasured, 5));
  printHelper.println(" V");

  float vinTest = voltageMeasured * ((R1 + R2) / R2);
  Serial.print("vinTest: ");
  Serial.print(vinTest, 5);
  Serial.println(" V");

  printHelper.print("vinTest: ");
  printHelper.print(String(vinTest, 5));
  printHelper.println(" V");

  // calculated correction
  float vinMeasuredCorrected =
      voltageMeasured * ((R1 + R2) / R2 * CORRECTION_FACTOR);
  Serial.print("vinMeasuredCorrected: ");
  Serial.print(vinMeasuredCorrected, 5);
  Serial.println(" V");

  printHelper.print("vinMeasuredCorrected: ");
  printHelper.print(String(vinMeasuredCorrected, 5));
  printHelper.println(" V");

  // exponential correction
  float vinTestCorrectedExponential = a * pow(vinTest, b);
  Serial.print("vinTestCorrectedExponential: ");
  Serial.print(vinTestCorrectedExponential, 5);
  Serial.println(" V");

  printHelper.print("vinTestCorrectedExponential: ");
  printHelper.print(String(vinTestCorrectedExponential, 5));
  printHelper.println(" V");

  return vinTestCorrectedExponential;
}

void voltageSensorSetup() {
  pinMode(ANALOG_IN_PIN, INPUT);

  for (int i = 0; i < READING_VOLTAGE_BUFFER; i++) {
    voltageReadings[i] = readVoltage();
    totalVoltage += voltageReadings[i];
  }
}

void voltageCheckAndRestartIfFailed(float *reading, int32_t *failedReadings) {
  printHelper.println("Checking if reading failed");
  if (reading == nullptr || std::isnan(*reading)) {
    printHelper.printf("Reading: %s", String(*reading));
    failedReadings += 1;
    printHelper.printf("Failed count: %s", String(*failedReadings));
    if (*failedReadings >= 10) {
      ESP.restart();
    }
  } else {
    printHelper.println("Reading OK");
    printHelper.printf("Reading: %s", String(*reading));
    failedReadings = 0;
  }
}

void readAndWriteVoltageSensor() {
  static uint32_t lastToggleTime = 0;

  if (millis() - lastToggleTime >= READ_VOLTAGE_DELAY) {
    int arrayLength = sizeof(voltageReadings) / sizeof(voltageReadings[0]);

    lastToggleTime = millis();

    totalVoltage -= voltageReadings[readVoltageIndex];
    voltageReadings[readVoltageIndex] = readVoltage();
    totalVoltage += voltageReadings[readVoltageIndex];

    voltageCheckAndRestartIfFailed(&totalVoltage, &failedVoltageReadings);

    readVoltageIndex = (readVoltageIndex + 1) % arrayLength;
    averageVoltage = totalVoltage / arrayLength;

    DynamicJsonDocument doc(1024);
    char buffer[256];

    doc["voltage"] = averageVoltage;

    size_t n = serializeJson(doc, buffer);

    bool published = client.publish(MQTT_STATETOPIC.c_str(), buffer, n);

    Serial.print("Published: ");
    Serial.println(published);
    // Debugging
    printHelper.print("Published: ");
    printHelper.println(String(published));

    Serial.print("Battery Voltage: ");
    Serial.print(averageVoltage);
    Serial.println(" V");
    // Debugging
    printHelper.print("Battery Voltage: ");
    printHelper.println(String(averageVoltage));
  }
}

#endif  // SRC_VOLTMETERCONTROLLER_H_

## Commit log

2023-11-26 controll device
2024-03-27 feat: add support for BME280 sensor
2024-03-29 chore: change temperature offset and naming
2024-03-30 refactor: combine DHT and BME sensor logic
2024-04-20 feat: restart ESP if temp or humid fail 10 times
    [SensorController.h]
2024-09-10 chore: print failed count if reading fails
    [SensorController.h]
2024-11-24 feat: add voltmeter function
2024-12-01 chore: calibrate temperature and humidity, calibrate voltage for 12V
2024-12-03 docs: circuit diagrams (#6)
    * docs: circuit diagrams
    * chore: add new line
2024-12-16 feat: voltmeter exponential correction (#10)
    * feat: voltmeter exponential correction
    * chore: correct CORRECTION_FACTOR
    [SensorController.h, VoltmeterController.h]
2024-12-18 feat: clear discovered devices on mqtt connect (#15)
    * feat: clearDiscoveredDevices on mqtt connect
    * chore: update liz
    * chore: print when clearing devices
    * chore: update liz
2024-12-31 feat: Add disconnect wifi button and update resistor values (#16)
    * refactor: formatting
    * refactor: linting and formatting
    * docs: update voltmeter drawing and added geogebra
    * chore: change resistor value
    * feat: add disconnect wifi button
    * chore: formatting
    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
2025-01-05 docs: calibration documentation (#19)
    * docs: calibration documentation
    * chore: calibration data
    * docs: voltmeter precision
    * docs: calibration data
    * docs: voltmeter drawing
    * docs: power consumption
    * docs: calibration data
    * chore: update copyright date
    * chore: set default liz type
    * chore: fix linting errors
    [SensorController.h, VoltmeterController.h, WIFIHelper.h]
2025-02-07 feat: esp32
2025-02-07 chore: add kicad files
    [1N5819.step, 3D_MODEL_D3V3XA4B10LP-7.stp, 6.3 SIZE CODE D8.stp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]
2025-02-07 chore: change resistor values
2025-06-07 refactor: move logic to cpp files (#36)
    * refactor: move logic to cpp files
    * chore: change i2c to io 18, 17 to match custom board
    * refactor: move logic to cpp files
    * chore(lib): update liz library
    * chore: set localudpport static and add i2c to build config
    * chore: make localudpport const
2025-06-26 chore: rename pcb folders (#40)
    [INPAQ WIP201610P-2R2ML v1.step, bom.csv, designators.csv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]
2025-06-29 chore: eeprom-esp32 (#51)
